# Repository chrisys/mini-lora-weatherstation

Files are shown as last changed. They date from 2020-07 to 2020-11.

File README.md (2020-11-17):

# Mini LoRa weatherstation

**This is a basic battery powered LoRa weather station based around a Bosch BME280 and Heltec CubeCell HTCC-AB01 development board. Data is sent via The Things Network (TTN) to your choice of dashboard!**

Thanks to the built in battery management and solar charging functionality of this board, as well as ultra low power consumption, we're finally able to put LoRa-connected sensors almost anywhere we want! I started out with this board building a simple weather station based on a BME280 sensor to record temperature, humidity and barometric pressure and test how long a battery will last using this board.

**For a more deep dive into the build, check out my blog posts:**
* [Part 1: Build a simple solar-powered weather station with LoRa & The Things Network](https://www.balena.io/blog/build-a-simple-solar-powered-weather-station-with-lora-the-things-network/)
* [Part 2: Receive and store LoRa sensor data from TTN using a Raspberry Pi](https://www.balena.io/blog/receive-and-store-lora-sensor-data-from-ttn-using-a-raspberry-pi/)

## Hardware required
* Bosch BME280 breakout board ([AliExpress](https://www.aliexpress.com/item/32849462236.html) - I chose these because the pinout exactly matches that of the dev board enabling you to solder it straight on)
* Heltec CubeCell HTCC-AB01 ([AliExpress](https://www.aliexpress.com/item/4000200371092.html) - be sure to select the correct LoRa frequency for your country)
* 3.7V LiPo cell (I'm using a 650mAh one) with a micro JST connector
* **Optional:** 6V 110x60mm solar panel ([AliExpress](https://www.aliexpress.com/item/1851948.html))

## Other requirements
* [Arduino IDE](https://www.arduino.cc/en/main/software)
* SiLabs CP2104 Driver ([installation instructions](https://heltec-automation-docs.readthedocs.io/en/latest/general/establish_serial_connection.html))
* CubeCell framework added to Arduino IDE ([installation instructions](https://heltec-automation-docs.readthedocs.io/en/latest/cubecell/quick_start.html))
* A free TTN account ([register here](https://account.thethingsnetwork.org/register))
* A free Ubidots STEM account ([register here](https://ubidots.com/stem/))
* You need to be in range of a TTN gateway ([here's a map](https://www.thethingsnetwork.org/map)) or have [built your own gateway](https://www.balena.io/blog/build-a-ttn-lora-gateway-with-balenafin-and-balenacloud/).

## TTN configuration
To decode the data on the TTN side, a custom payload format decoder function is required. This is included in `payload-decode.txt`. Simply paste the contents of this file into the `Decoder` input area under `Payload Formats` within the TTN console.

## For the case

I used a Creality Ender 3 loaded with white PETG filament to print this case. Word has it that PETG is a good material to use for outdoor items that are going to be exposed to weather and UV. Time will tell.

* 1x Base (mini-lora-ws-base.stl)
* 6x Open layers (mini-lora-ws-openlayer.stl)
* 1x Closed layer (mini-lora-ws-closedlayer.stl)
* 1x Top layer (mini-lora-ws-top.stl)
* **Optional:** 1x Solar panel bracket
* M4 tap
* M4 stainless steel machine screws (for securing the top layer)
* M2 tap
* M2 stainless steel machine screws (for securing the CubeCell board to the base)

The holes in the top of the posts and in the upright stand for the CubeCell board on the base are tapping size for M4 and M2 respectively. This means that after it is printed you can run a standard tap into the hole and get some decent quality threads.

## Assembly

Once you've printed the parts they should fit together - tolerances should be large enough to cater for minor variations in prints but you may need to clean up the edges of the holes in the layers if your first layer is a bit squashed.

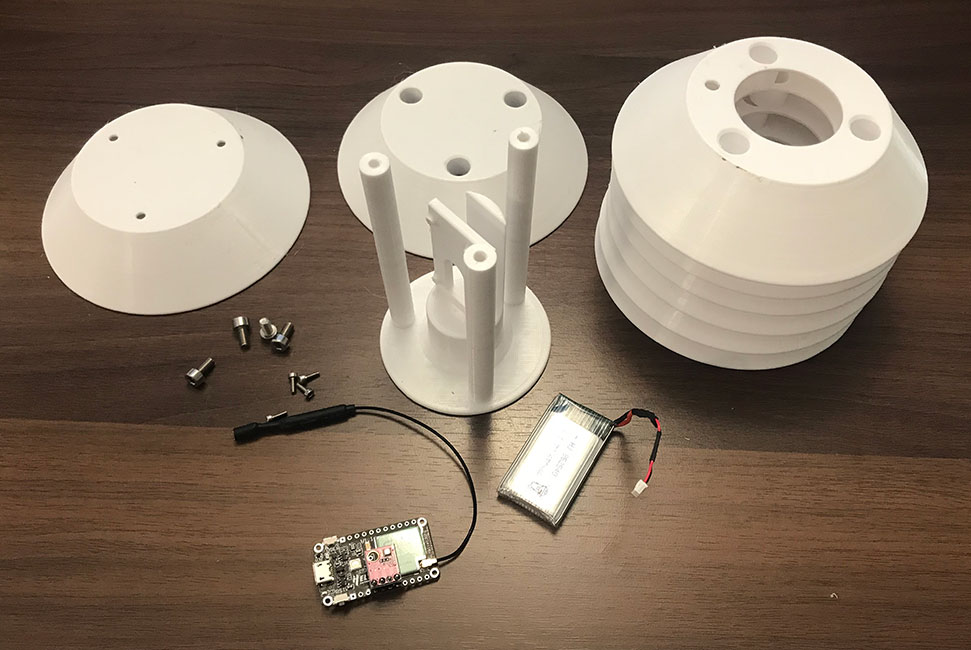
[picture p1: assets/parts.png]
parts


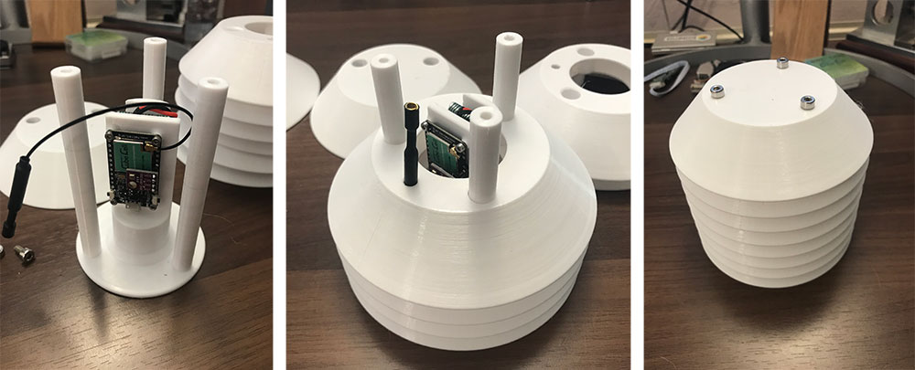
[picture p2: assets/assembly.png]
assembly


If you're adding a solar panel that layer can be placed between the top layer and the bracket.

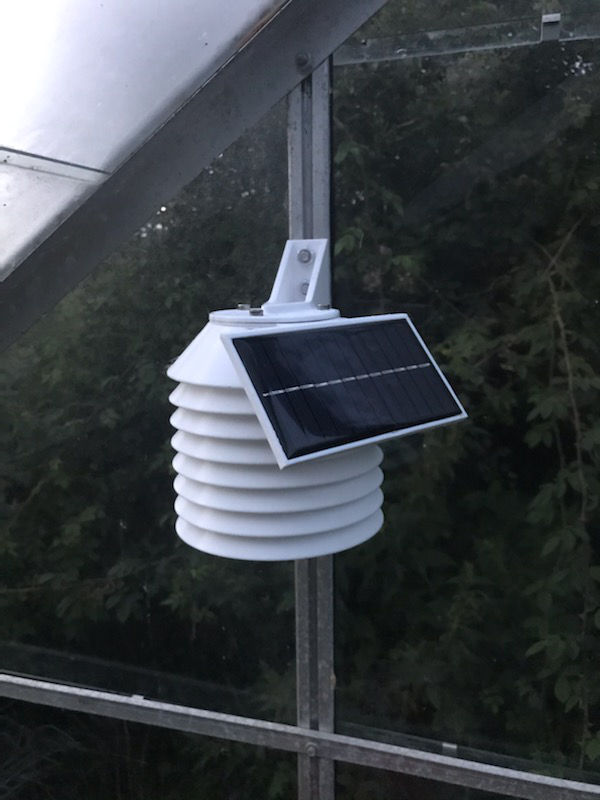
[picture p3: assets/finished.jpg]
finished


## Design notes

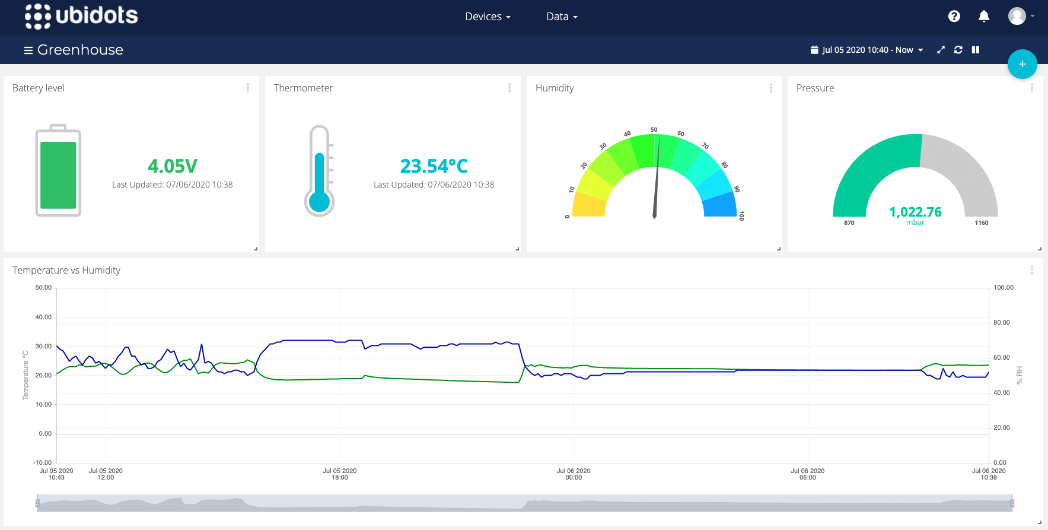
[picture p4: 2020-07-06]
assets/dashboard.png

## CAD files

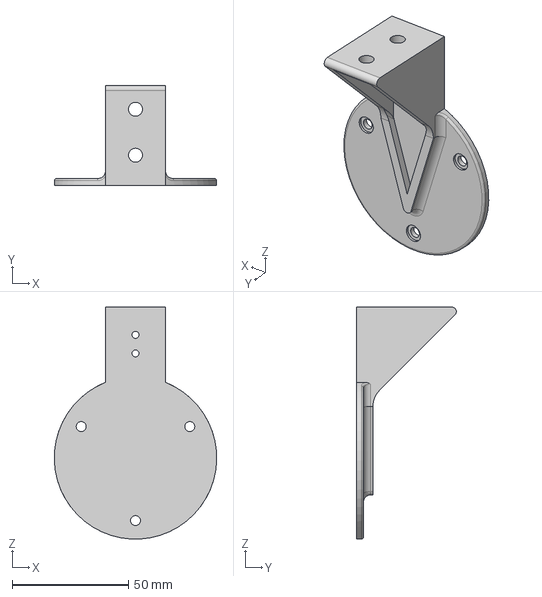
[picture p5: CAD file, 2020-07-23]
housing/mini-lora-ws-bracket.step
70.0 x 43.0 x 99.9 mm

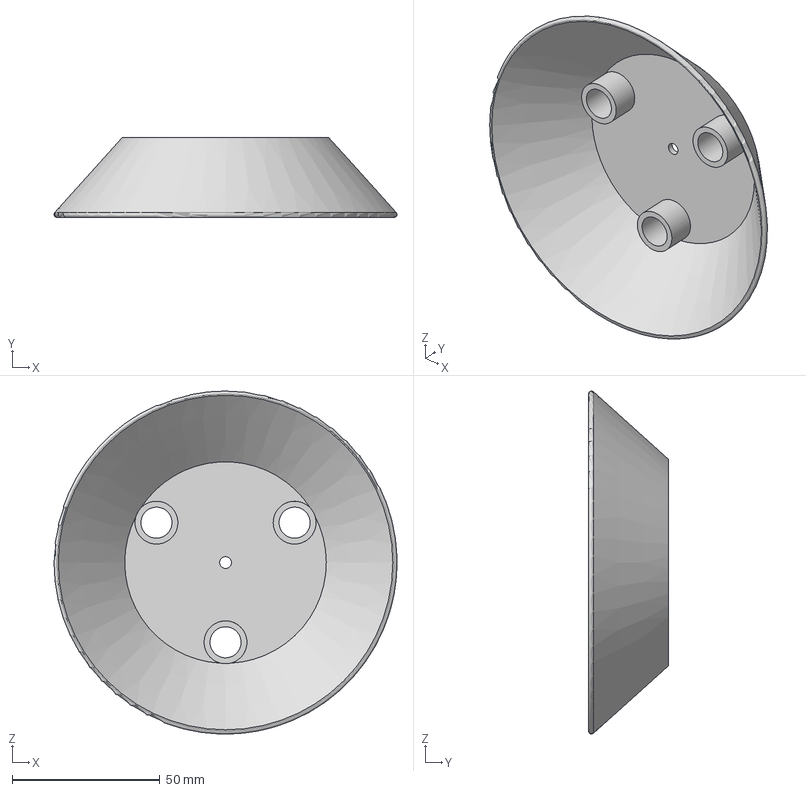
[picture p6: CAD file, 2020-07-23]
housing/mini-lora-ws-closedlayer.step
116.1 x 27.0 x 116.1 mm

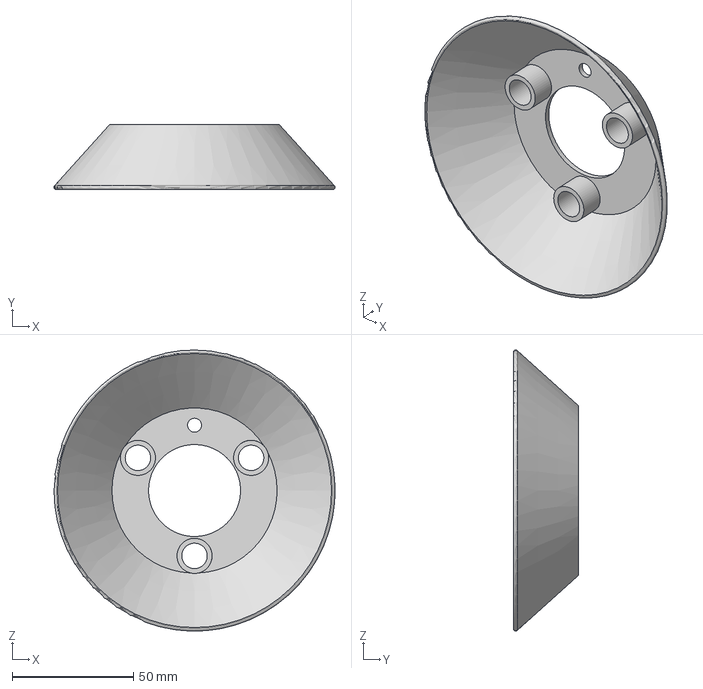
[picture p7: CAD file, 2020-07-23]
housing/mini-lora-ws-openlayer.step
116.1 x 27.0 x 116.1 mm

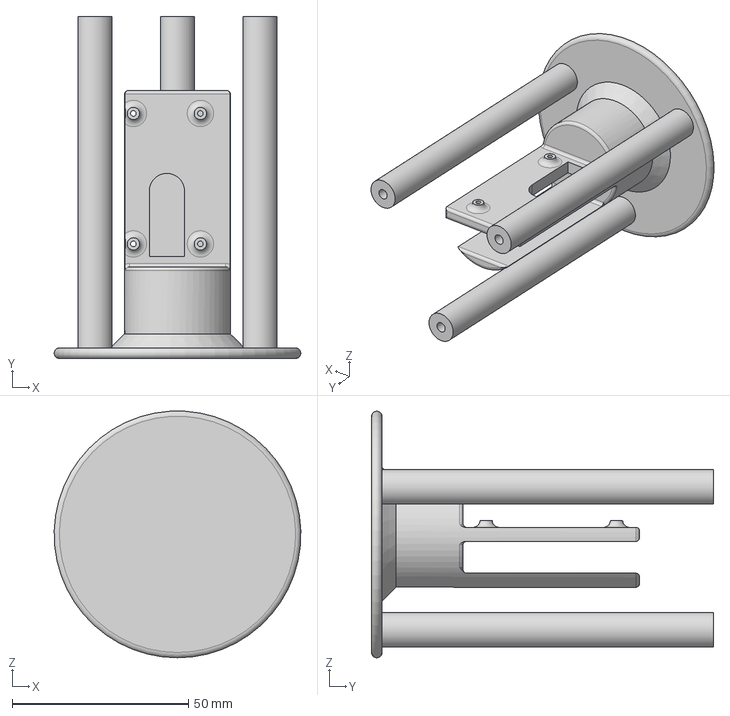
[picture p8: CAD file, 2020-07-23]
housing/mini-lora-ws-base.step
70.0 x 97.0 x 69.9 mm

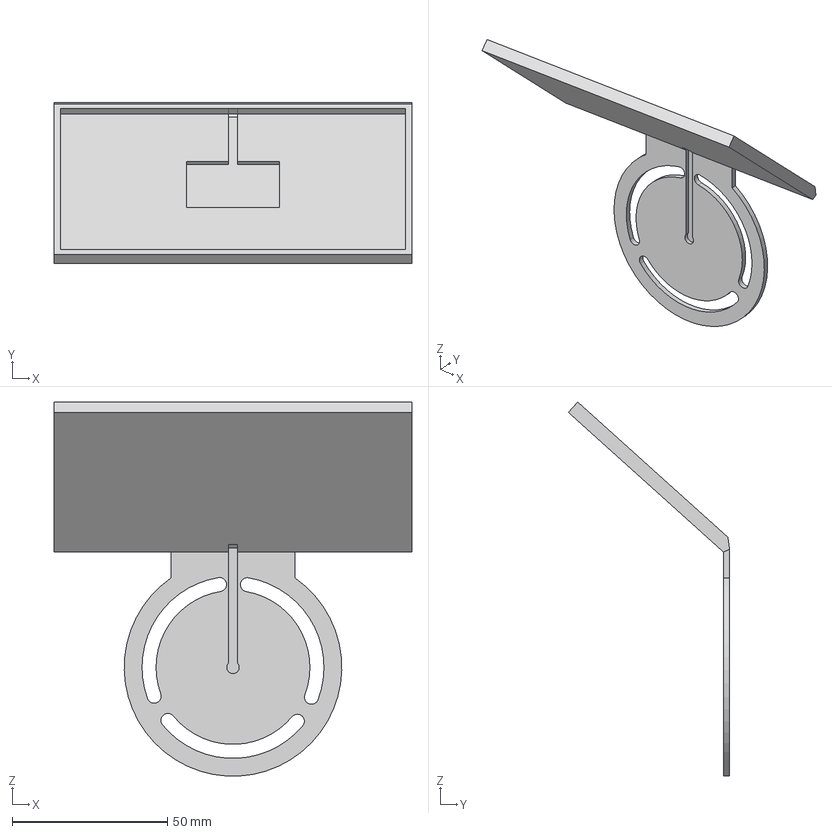
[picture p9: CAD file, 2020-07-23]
housing/mini-lora-ws-solar.step
115.0 x 51.9 x 120.3 mm

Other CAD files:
housing/mini-lora-ws-top.step
housing/mini-lora-ws-base.stl
housing/mini-lora-ws-bracket.stl
housing/mini-lora-ws-closedlayer.stl
housing/mini-lora-ws-openlayer.stl
housing/mini-lora-ws-solar.stl
housing/mini-lora-ws-top.stl

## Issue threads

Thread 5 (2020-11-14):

Sub-zero temperatures

grz3chu, 2020-11-14:
Hi,

Unfortunately, the station does not show sub-zero temperatures.

Here the issue is probably resolved, but now I don't have a board to check it out:
https://github.com/kizniche/ttgo-tbeam-sensor-node-bme280 (sflt162f function)

grz3chu, 2020-11-20:
Thank you, it works now. In Poland today we have first sub-zero temperature.

https://iot.devnull.waw.pl
https://iot.devnull.waw.pl/charts.php

Closed 2020-11-17.

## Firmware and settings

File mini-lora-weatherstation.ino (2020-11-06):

#include <LoRaWan_APP.h>
#include <Arduino.h>
#include <Seeed_BME280.h>
#include <Wire.h>
#include "ttnparams.h"

bool ENABLE_SERIAL = false; // enable serial debug output here if required
uint32_t appTxDutyCycle = 300000; // the frequency of readings, in milliseconds(set 300s)

uint16_t userChannelsMask[6]={ 0x00FF,0x0000,0x0000,0x0000,0x0000,0x0000 };
LoRaMacRegion_t loraWanRegion = ACTIVE_REGION;
DeviceClass_t  loraWanClass = LORAWAN_CLASS;
bool overTheAirActivation = LORAWAN_NETMODE;
bool loraWanAdr = LORAWAN_ADR;
bool keepNet = LORAWAN_NET_RESERVE;
bool isTxConfirmed = LORAWAN_UPLINKMODE;
uint8_t appPort = 2;
uint8_t confirmedNbTrials = 4;

int temperature, humidity, batteryVoltage, batteryLevel;
long pressure;

BME280 bme280;

static void prepareTxFrame( uint8_t port )
{
  // This enables the output to power the sensor
  pinMode(Vext, OUTPUT);
  digitalWrite(Vext, LOW);
  delay(500);

  if(!bme280.init()){
    if(ENABLE_SERIAL){
      Serial.println("Device error!");
    }
  }

  // This delay is required to allow the sensor time to init
  delay(500);
  
  temperature = bme280.getTemperature() * 100;
  humidity = bme280.getHumidity();
  pressure = bme280.getPressure();
  
  Wire.end();
  
  // Turn the power to the sensor off again
  digitalWrite(Vext, HIGH);
  
  batteryVoltage = getBatteryVoltage();
  batteryLevel = (BoardGetBatteryLevel() / 254) * 100; 

  appDataSize = 12;
  appData[0] = highByte(temperature);
  appData[1] = lowByte(temperature);

  appData[2] = highByte(humidity);
  appData[3] = lowByte(humidity);

  appData[4] = (byte) ((pressure & 0xFF000000) >> 24 );
  appData[5] = (byte) ((pressure & 0x00FF0000) >> 16 );
  appData[6] = (byte) ((pressure & 0x0000FF00) >> 8  );
  appData[7] = (byte) ((pressure & 0X000000FF)       );

  appData[8] = highByte(batteryVoltage);
  appData[9] = lowByte(batteryVoltage);

  appData[10] = highByte(batteryLevel);
  appData[11] = lowByte(batteryLevel);

  if(ENABLE_SERIAL){
    Serial.print("Temperature: ");
    Serial.print(temperature / 100);
    Serial.print("C, Humidity: ");
    Serial.print(humidity);
    Serial.print("%, Pressure: ");
    Serial.print(pressure / 100);
    Serial.print(" mbar, Battery Voltage: ");
    Serial.print(batteryVoltage);
    Serial.print(" mV, Battery Level: ");
    Serial.print(batteryLevel);
    Serial.println(" %");
  }
}

void setup()
{
  
  boardInitMcu();
  if(ENABLE_SERIAL){
    Serial.begin(115200); 
  }
  deviceState = DEVICE_STATE_INIT;
  LoRaWAN.ifskipjoin();

}

void loop()
{
  switch( deviceState )
  {
    case DEVICE_STATE_INIT:
    {
      printDevParam();
      LoRaWAN.init(loraWanClass,loraWanRegion);
      deviceState = DEVICE_STATE_JOIN;
      break;
    }
    case DEVICE_STATE_JOIN:
    {
      LoRaWAN.join();
      break;
    }
    case DEVICE_STATE_SEND:
    {
      prepareTxFrame( appPort );
      LoRaWAN.send();
      deviceState = DEVICE_STATE_CYCLE;
      break;
    }
    case DEVICE_STATE_CYCLE:
    {
      // Schedule next packet transmission
      txDutyCycleTime = appTxDutyCycle + randr( 0, APP_TX_DUTYCYCLE_RND );
      LoRaWAN.cycle(txDutyCycleTime);
      deviceState = DEVICE_STATE_SLEEP;
      break;
    }
    case DEVICE_STATE_SLEEP:
    {
      LoRaWAN.sleep();
      break;
    }
    default:
    {
      deviceState = DEVICE_STATE_INIT;
      break;
    }
  }
}

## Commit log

2020-07-06 Added housing STLs and more readme
    Change-type: patch
    [mini-lora-ws-base.stl, mini-lora-ws-closedlayer.stl, mini-lora-ws-openlayer.stl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]
2020-07-23 Added solar details and step files
    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
    [mini-lora-ws-base.step, mini-lora-ws-bracket.step, mini-lora-ws-bracket.stl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]
2020-11-03 Add Battery Level
2020-11-10 Update payload-decode.txt
    Battery lebel Bug fix
